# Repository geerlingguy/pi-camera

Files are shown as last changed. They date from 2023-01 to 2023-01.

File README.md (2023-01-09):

# Raspberry Pi Camera

This project has the files and information required to build a compact and portable Raspberry Pi camera.

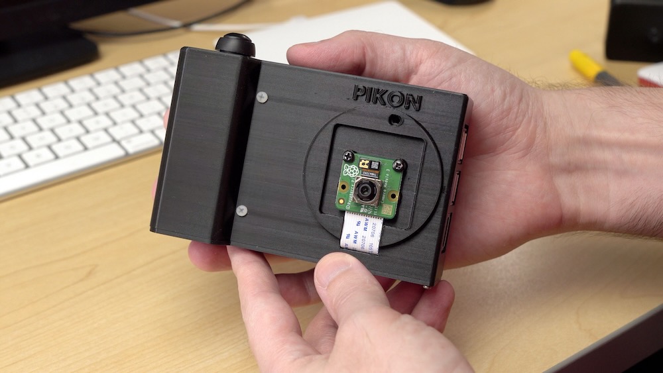
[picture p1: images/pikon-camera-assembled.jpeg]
Raspberry Pi Camera assembled


The project is based around the Pi Camera v3, which has autofocus and a 12 megapixel sensor, but any compatible camera module can work (including Arducam's higher-resolution or autofocus cameras).

It is _most definitely_ a work in progress, and you will probably need to do a little extra work to get your own Pi Camera going.

Inspiration:

  - [RUHAcam](https://github.com/penk/ruha.camera) by [@penk](https://github.com/penk)
  - [PIKON Camera](https://www.kevsrobots.com/blog/pikon-camera.html) by [Kevin McAleer](https://www.kevsrobots.com)

If you run into any problems, or have suggestions for improving the design, assembly, or code to run the camera, plase feel free to open an issue.

## Video

I posted a video detailing the assembly and testing of this camera project on YouTube: [https://www.youtube.com/watch?v=1EIFfln3Kxs](https://www.youtube.com/watch?v=1EIFfln3Kxs).

## Assembling the Camera

### Parts required

  - Raspberry Pi 4 model B (2 GB RAM or better)
  - Raspberry Pi Camera Module 3 (Other camera modules should work too!)
  - [SanDisk Extreme 128GB microSD card](https://amzn.to/3GnJ1BM)
  - [Waveshare 3.5" TFT GPIO LCD](https://amzn.to/3ZdFley)
  - [Twidec 12mm momentary push button](https://amzn.to/3ijIj0C)
  - [2x4 2.54mm Female Headers](https://amzn.to/3CrlQ8H)
  - USB-C battery bank and USB-C cable for powering the Pi
  - Screws and nuts:
    - M2.5x12mm x4, with a nut for each screw (for Pi)
    - M2.5x4mm (screw) x4 (for front camera attachment)
    - M2x5mm x2 (for bottom plate)

### 3D Printed Enclosure

You can basically duck-tape together the rig if you squish the camera cable in between the Pi and the Waveshare screen, and tape the button somewhere. But that's not very elegant.

So instead, I [adapted the 'PIKON' design](https://www.kevsrobots.com/blog/pikon-camera.html) from Kevin McAleer, and modified it to fit the 12mm pushbutton for the shutter, and a Pi Camera v3 instead of the HQ camera.

More tweaks to the 3D case design should be made, to make it a little more organic/comfortable, and to better fit the parts (especially if we can get an 18650 rechargeable battery in there!).

For now, the current version of the case is split into two parts: the main enclosure, and the bottom cover. You can find the STL files inside the `enclosure` directory.

### Assembly

  1. Solder the 12mm pushbutton leads onto the first and last pin on one of the 2x4 female headers. (In my setup, I have one lead going to a ground pin, and the other to GPIO pin 21. Your setup may vary, depending on how you attach the pushbutton.)
  1. Route the camera module cable in through the slit on the front of the enclosure.
  1. Screw the camera module into the enclosure using M2.5 4mm screws. (Note: These screws will embed themselves into the PCB a little as you screw them in.)
  1. Insert the Raspberry Pi into the enclosure, with the ports facing out the left side.
  1. Screw the Raspberry Pi into the four standoffs using M2 12mm screws threaded from the outside, held in place with nuts on the inside on top of the Pi.
  1. Plug the camera module cable into the Pi's Camera CSI connector, making sure the exposed pins face the port side of the board.
  1. Plug the pre-soldered pushbutton header into the GPIO pins so the two connections go to ground and GPIO pin 21. Gently bend the connecting wires so they do not push against the display.
  1. Install the Waveshare GPIO TFT display on the GPIO header. The display should be fixed directly on top of the Pi 4 model B itself.
  1. Gently tuck the camera module cable behind the display.
  1. Screw the bottom plate onto the enclosure with 2 M2 screws.

## Raspberry Pi OS Setup

Flash the latest version of Raspberry Pi OS (64-bit preferred) to a fresh microSD card, and insert the microSD card into your Pi, and boot it up.

> I did all my configuration over SSH, but you could plug in an external HDMI display and a keyboard, and configure it that way too.

In a Terminal window or via SSH, run:

```
sudo raspi-config
```

  1. Under 'System Options', go to the 'Boot / Auto Login' settings and choose 'Desktop auto-login'.
  1. Under 'Display Options', go to 'Screen Blanking' and choose 'No'.
  1. Reboot the Pi when asked.

### LCD Setup

If using a different model display, be sure to look up the instructions for that display. In my case, I read through [Waveshare's documentation for the 3.5" LCD (A)](https://www.waveshare.com/wiki/3.5inch_RPi_LCD_(A)). To set up the display:

  1. `git clone https://github.com/waveshare/LCD-show.git`
  1. `cd LCD-show`
  1. `chmod +x LCD35-show`
  1. `./LCD35-show`

Running this script destructively changes the `/boot/config.txt` file, though, and will break the ability to use the Camera Module v3. So you need to edit your `/boot/config.txt` file and make sure the configuration matches the `config.txt` file included in this repository.

Copy over the contents of this repo's `config.txt` file, then reboot the Pi.

You should see the Pi boot into Raspberry Pi OS, logged in on the desktop.

## Pi Camera Software (Picamera2)

The Pi is now ready to be used as a camera. Either via SSH, or with a keyboard and mouse plugged into the Pi itself, test that the camera is working:

```
libcamera-hello -t 0 --autofocus-mode continuous
```

That should pop up a preview window, and show the camera feed live on the display. If you don't see a feed, press Ctrl + C to exit, and then run the same command, with `--qt-preview` on the end.

> When operating the camera over SSH, the Pi will not know what display to use for previews. You need to explicitly use 'Display 0' so previews appear on the 3.5" display:
>
> ```
> export DISPLAY=:0
> ```

To make the camera work as a _camera_, with the pushbutton taking an image, copy the `camera.py` file into your home directory, and make it executable:

```
chmod +x camera.py
```

Then test that it's working by running:

```
./camera.py
```

A preview window should appear on the screen, and if you click the button, it should take a picture, placing it inside `~/Pictures`.

### Enabling the camera at boot

Instructions for making the camera start at system boot using `systemd` will be added soon.

## License

MIT

## Author

[Jeff Geerling](https://www.jeffgeerling.com/)

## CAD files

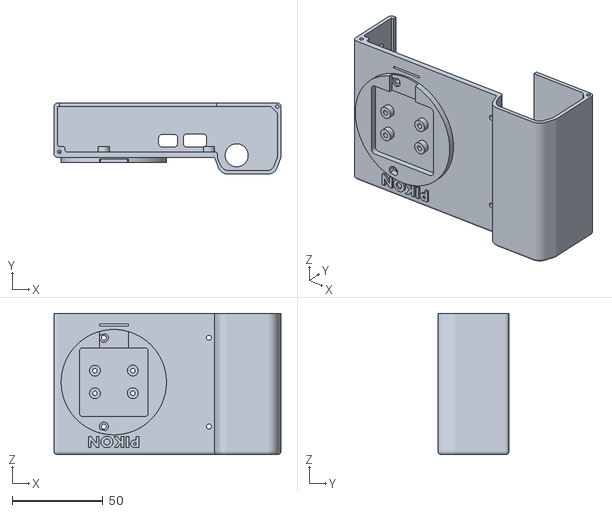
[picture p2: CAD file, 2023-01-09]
enclosure/Pikon Camera Case v2.stl
125.3 x 39.3 x 78.0

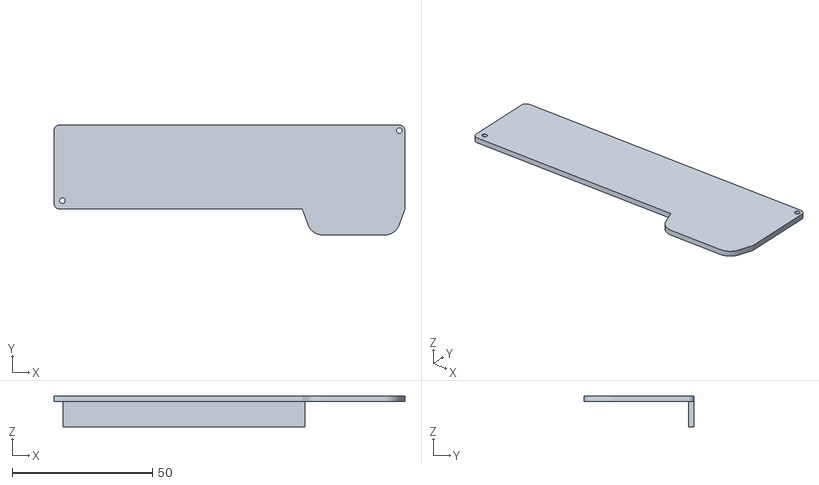
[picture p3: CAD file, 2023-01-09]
enclosure/Pikon Camera Bottom v3.stl
125.3 x 39.3 x 11.0

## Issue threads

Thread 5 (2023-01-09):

Use crontab rather than systemd for starting the camera up on boot

lolpro11, 2023-01-09:
Why use a systemd module rather than using a crontab entry like this:

```
@reboot bash -c "export DISPLAY=:0; libcamera-hello -t 0 --autofocus-mode continuous"
```
I think that having a crontab script is easier than creating a systemd module.

trevor-viljoen, 2023-01-09:
systemd is already used to manage processes. It has pretty good built in logging which is easier than trying to grep through logs to find out what is going on for a given cron command. It allows for a service (what) to be defined and to run with a given timer (when). All of this is declarative and easily maintained in code. I think the pros of systemd outweigh the cons.

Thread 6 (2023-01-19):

problem with driver

realjanek, 2023-01-19:
Thanks for sharing your work. When invoked from command line, I have a nice video from camera. I have problem with accessing video using Chromium browser on RPi with an error "User media request denied with error code 0". It works with USB webcam on the same system. How to resolve it?

realjanek, 2023-01-19:
tested here https://webrtc.github.io/samples/src/content/devices/input-output/

realjanek, 2023-01-20:
more info: the camera is being seen as unicam (see attached screenshot) but shows only black screen when selected. Should I start it somehow? (forgive my limited knowledge of Linux)
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

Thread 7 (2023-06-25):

Struggling

skyeshadow94, 2023-06-25:
Running without a screen.... get this please help

$ python3 camera.py
[0:02:09.519915828] [1708]  INFO Camera camera_manager.cpp:299 libcamera v0.0.4+                                                                                                                                                             22-923f5d70
[0:02:09.647716734] [1718]  INFO RPI raspberrypi.cpp:1476 Registered camera /bas                                                                                                                                                             e/soc/i2c0mux/i2c@1/imx708@1a to Unicam device /dev/media1 and ISP device /dev/m                                                                                                                                                             edia3
qt.qpa.xcb: could not connect to display
qt.qpa.plugin: Could not load the Qt platform plugin "xcb" in "" even though it                                                                                                                                                              was found.
This application failed to start because no Qt platform plugin could be initiali                                                                                                                                                             zed. Reinstalling the application may fix this problem.

Available platform plugins are: eglfs, linuxfb, minimal, minimalegl, offscreen,                                                                                                                                                              vnc, xcb.

Aborted

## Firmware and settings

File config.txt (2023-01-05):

# For more options and information see
# http://www.raspberrypi.org/documentation/configuration/config-txt.md
# Some settings may impact device functionality. See link above for details
arm_64bit=1

# uncomment if you get no picture on HDMI for a default "safe" mode
#hdmi_safe=1

# uncomment this if your display has a black border of unused pixels visible
# and your display can output without overscan
#disable_overscan=1

# uncomment the following to adjust overscan. Use positive numbers if console
# goes off screen, and negative if there is too much border
#overscan_left=16
#overscan_right=16
#overscan_top=16
#overscan_bottom=16

# uncomment to force a console size. By default it will be display's size minus
# overscan.
#framebuffer_width=1280
#framebuffer_height=720

# uncomment if hdmi display is not detected and composite is being output
hdmi_force_hotplug=1

# uncomment to force a specific HDMI mode (this will force VGA)
#hdmi_group=1
#hdmi_mode=1

# uncomment to force a HDMI mode rather than DVI. This can make audio work in
# DMT (computer monitor) modes
#hdmi_drive=2

# uncomment to increase signal to HDMI, if you have interference, blanking, or
# no display
#config_hdmi_boost=4

# uncomment for composite PAL
#sdtv_mode=2

#uncomment to overclock the arm. 700 MHz is the default.
#arm_freq=800

# Uncomment some or all of these to enable the optional hardware interfaces
dtparam=i2c_arm=on
#dtparam=i2s=on
dtparam=spi=on
enable_uart=1
# Uncomment this to enable the lirc-rpi module
#dtoverlay=lirc-rpi

# Additional overlays and parameters are documented /boot/overlays/README

# Enable audio (loads snd_bcm2835)
dtparam=audio=on

# Automatically load overlays for detected cameras
camera_auto_detect=1

# Waveshare 3.5 inch display
dtoverlay=waveshare35a
hdmi_force_hotplug=1
hdmi_group=2
hdmi_mode=1
hdmi_mode=87
hdmi_cvt 480 320 60 6 0 0 0
hdmi_drive=2

# Automatically load overlays for detected DSI displays
#display_auto_detect=1

# Enable DRM VC4 V3D driver
#dtoverlay=vc4-kms-v3d
dtoverlay=vc4-fkms-v3d
max_framebuffers=1

# Disable compensation for displays with overscan
#disable_overscan=1

[cm4]
# Enable host mode on the 2711 built-in XHCI USB controller.
# This line should be removed if the legacy DWC2 controller is required
# (e.g. for USB device mode) or if USB support is not required.
otg_mode=1

[pi4]
# Run as fast as firmware / board allows
arm_boost=1

[all]
dtoverlay=imx708,vcm

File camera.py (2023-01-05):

#!/usr/bin/env python3
from gpiozero import Button
from libcamera import controls
from picamera2 import Picamera2, Preview
import time

button = Button(21)

with Picamera2() as picam2:
    frame = int(time.time())

    # Set up QT preview window.
    picam2.start_preview(Preview.QT)
    preview_config = picam2.create_preview_configuration()
    capture_config = picam2.create_still_configuration()
    picam2.configure(preview_config)
    picam2.start()
    time.sleep(1)
    print("Preview started")

    # Turn on full-time autofocus.
    picam2.set_controls({"AfMode": 2 ,"AfTrigger": 0})

    # Wait for button press. When pressed, take picture.
    while True:
        button.wait_for_press()
        filename = '/home/pi/Pictures/%03d.jpg' % frame
        picam2.switch_mode_and_capture_file(capture_config, filename)
        print ('Image captured: ' + filename)
        frame += 1

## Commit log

2023-01-05 Initial commit.
    [config.txt]
2023-01-06 Add a camera module as a requirement, lol.
2023-01-09 Add case enclosure STL files and an image for the README.
    [Pikon Camera Bottom v3.stl, Pikon Camera Case v2.stl]
